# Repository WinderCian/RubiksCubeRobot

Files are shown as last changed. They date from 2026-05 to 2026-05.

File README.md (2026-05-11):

This repo contains the CAD Models and Python Code for my Final Year Project at Maynooth University.
Feel free to use and build off of.

Here is a Link to a few Videos of the Robot Running:
https://www.youtube.com/@RubikCubeC%C3%ADan

Cían Winder
cian.winder.2022@mumail.ie
cjiwinder2@gmail.com
21424916

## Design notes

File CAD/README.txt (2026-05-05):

--------// Rubik's Cube Solver Frame //----------

This folder contains the CAD Models for the RubiksCubeSolver. In order to create the whole robot you need:

 1 × Base Plate
 1 × Top Plate
 4 × Side Mount Plate
 6 × Centre Cap Grip
 6 × Motor Rod
 24 × Nuts & Bolts (M3 × 10mm) 

Cían Winder
cian.winder.2022@mumail.ie
cjiwinder2@gmail.com
21424916

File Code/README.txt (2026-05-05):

--------// Raspberry Pi Rubik's Cube Solver //----------

Below are the instructions on using the Rubik's Cube Solving Robot. 
The motors should be connected to their corresponding drivers which in turn should be connected to the correct GPIO pins.

From Top to Bottom (Breadboard Oriented with 24V Power in Top Right) the drivers correspond as:
1st Driver - Up Motor (Yellow Face)   - Step Pin: 27, Direction Pin: 22
2nd Driver - Back Motor (Orange Face) - Step Pin: 23, Direction Pin: 24
3rd Driver - Right Motor (Green Face) - Step Pin: 12, Direction Pin: 16
4th Driver - Left Motor (Blue Face)   - Step Pin: 5,  Direction Pin: 6
5th Driver - Front Motor (Red Face)   - Step Pin: 19, Direction Pin: 26
6th Driver - Down Motor (White Face)  - Step Pin: 20, Direction Pin: 21

INSTRUCTIONS.
1 - Unzip files into chosen folder
2 - Open 2 Tabs in Terminal.
3 - In both tabs, Navigate to Directory of the unzipped Python Files.
4 - In first terminal tab, Run 'Python ClientGui.py' and wait for it to open.
5 - Set HOST to 'localhost' and set PORT to '8080'
6 - Input net of cube into the GUI
7 - In second terminal tab, Run 'Python RubiksSolver.py'
8 - Wait until terminal reads 'Waiting for Solved String...'
9 - Turn on power to the Motors.
10 - In GUI click 'Solve' button.
11 - Wait until all motors stop moving.
12 - Cube is Solved :)

Cían Winder
cian.winder.2022@mumail.ie
cjiwinder2@gmail.com
21424916

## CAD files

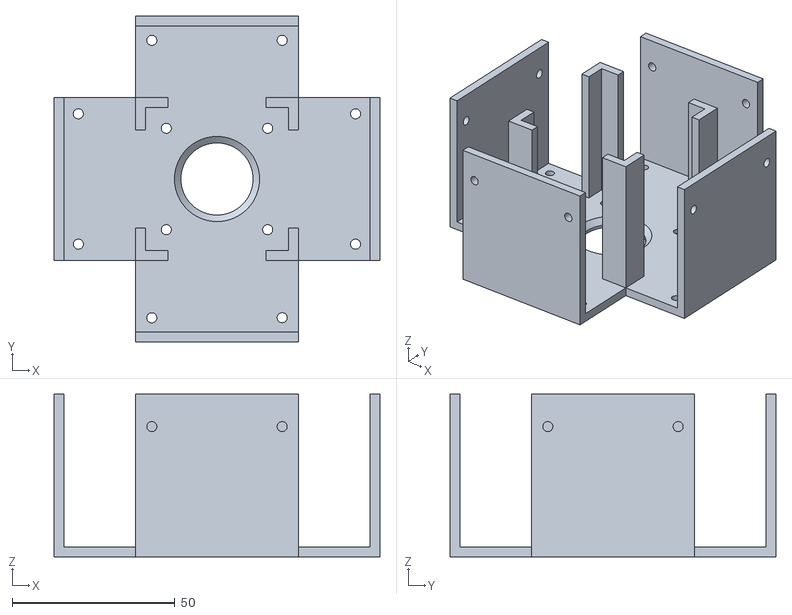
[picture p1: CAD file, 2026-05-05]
CAD/BasePlate.stl
100.0 x 100.0 x 50.0

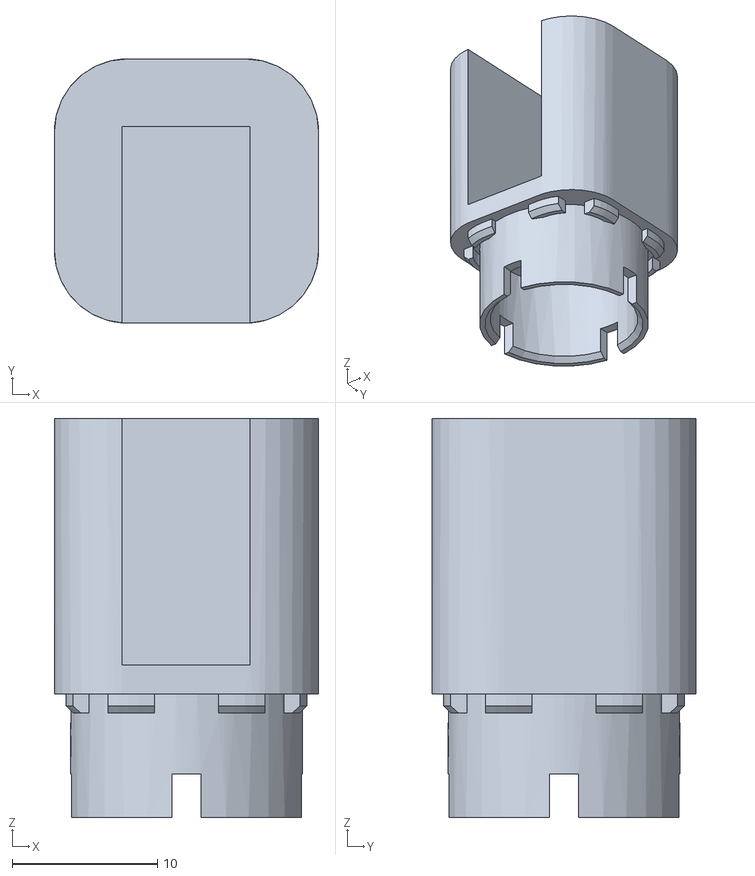
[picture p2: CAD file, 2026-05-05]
CAD/MagneticCubeGrip.stl
18.2 x 18.2 x 27.5

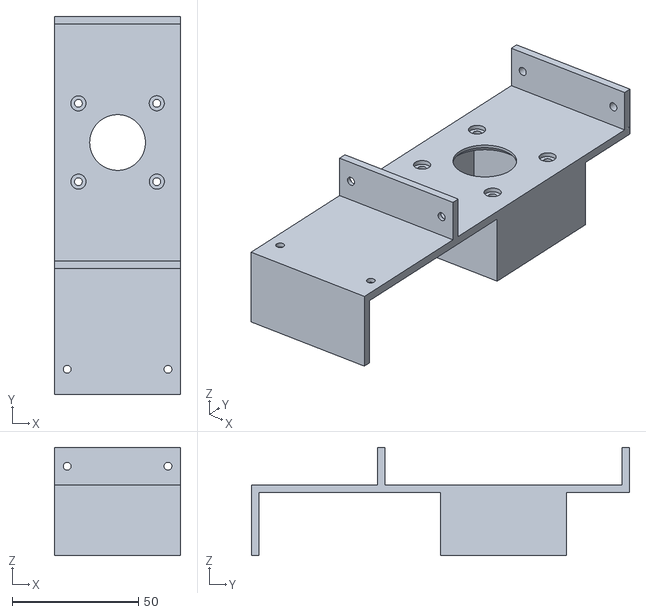
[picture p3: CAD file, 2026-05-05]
CAD/SideMount.stl
50.1 x 150.0 x 43.0

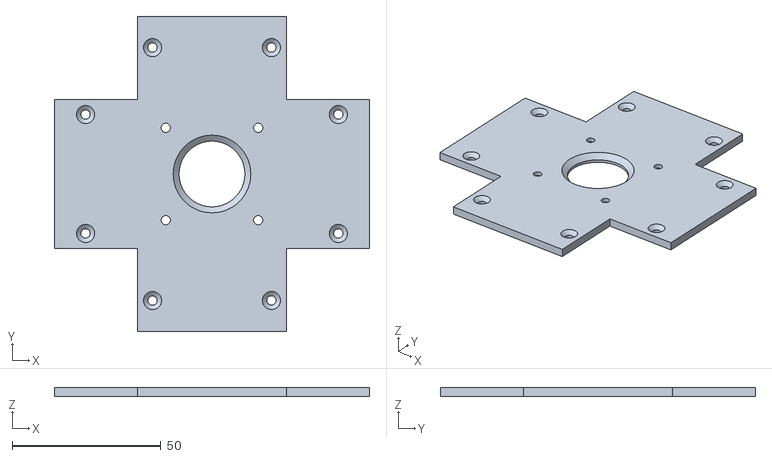
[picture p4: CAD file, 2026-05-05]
CAD/TopPlate.stl
106.0 x 106.0 x 3.00

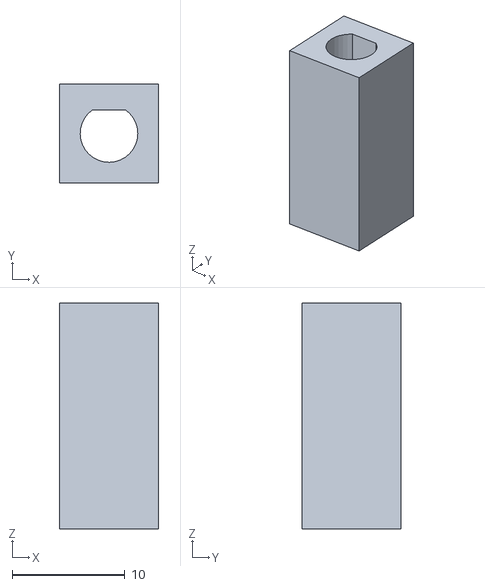
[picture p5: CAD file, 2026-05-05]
CAD/MotorRod.stl
8.80 x 8.80 x 20.0

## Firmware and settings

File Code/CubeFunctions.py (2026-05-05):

import RPi.GPIO as GPIO
import time
import socket

# Pin Numbers For Motors & Drivers
motors = {
    "U" : {"step": 27, "dir": 22},  # Yellow Face
    "B" : {"step": 23, "dir": 24},  # Orange Face
    "R" : {"step": 12,  "dir": 16}, # Green Face
    "L" : {"step": 5,  "dir": 6},   # Blue Face
    "F" : {"step": 19, "dir": 26},  # Red Face
    "D" : {"step": 20, "dir": 21},  # White Face
    }
    
# / ------ GPIO Setup ------ /
GPIO.setmode(GPIO.BCM)

for motor in motors.values():
    # Declare Each Motor Control Pin an Output
    GPIO.setup(motor["step"], GPIO.OUT)
    GPIO.setup(motor["dir"], GPIO.OUT)

def receiveSolution():
    # Function creates a localhost server to receive the string from the Client GUI
	HOST = "0.0.0.0"
	PORT = 8080

	server = socket.socket(socket.AF_INET, socket.SOCK_STREAM)
	server.bind((HOST, PORT))
	server.listen(1)

	print("Waiting for Solved String")

	conn, addr = server.accept()
	inputString = conn.recv(1024).decode()
	
	return inputString.strip()


def parseMoves(inputString):
    # Function takes the raw solve string from 'sv.solve()' and transforms it into a list with one element per move
    cleanString = inputString.split("(")[0].strip()
    solveString = cleanString.split()
    
    return (solveString)


def stepMotor(face, steps, direction):
    # Function turns the motor for the corresponding face, number of steps and in the correct direction
    GPIO.output(motors[face]["dir"], direction)

    for _ in range(steps):
        GPIO.output(motors[face]["step"], 1)
        time.sleep(0.005)
        GPIO.output(motors[face]["step"], 0)
        time.sleep(0.005)
        
    time.sleep(0.1)



def executeMove(move):
    # Function translates a move from its Cube notation to Motor instructions
    face = move[0]
    modifier = move[1:]

    motor = motors[face]
    direction = 1
    steps = 50
    
    if modifier == "3":
        direction = 0
        
    elif modifier == "2":
        steps = 100

    stepMotor(face, steps, direction)



def executeSolve(moves):
    # Function takes the list of moves and passes each of them throught the 'executeMove()' function
    for move in moves:
        print(f"Executing: {move}")
        executeMove(move)
    
    print("Cube Solved!")
    return 0
        
